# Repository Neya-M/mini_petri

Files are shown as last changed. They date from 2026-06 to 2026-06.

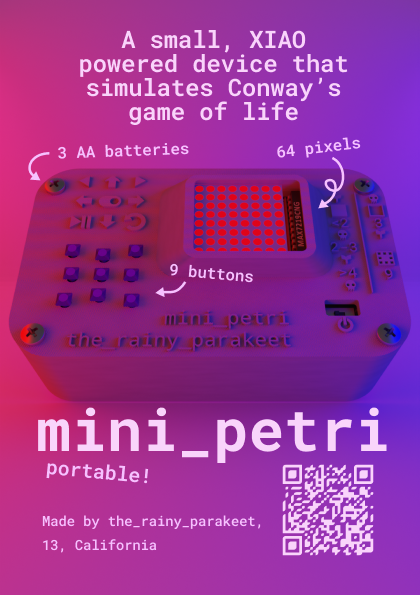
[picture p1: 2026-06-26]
images/zine/zine.png

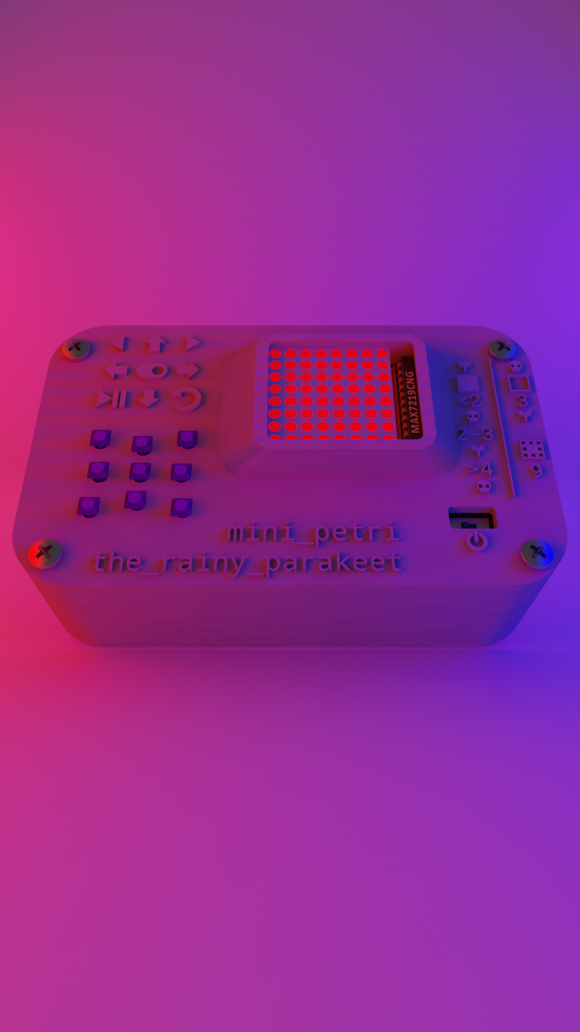
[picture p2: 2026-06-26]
images/render.png

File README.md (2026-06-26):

# Mini Petri

render of mini petri with case

Mini Petri is a device that simulates Conway's game of life. I got this idea during a particularly boring class when I wanted something satisfying to look at.

### Highlights

- runs on a Xiao RP2040 and 3 AA batteries
- 8x8 led dot matrix to give enough space for your life to grow
- 9 buttons to easily edit and play simulations 
- portable and pocket sized (8x13x5 cm)

Here is a banana for scale.

banana scale

## Build your own

render of mini petri pcb

Want a Mini Petri? Download the files in the "build" folder. Order the board with gerbers.zip. The case has 3d models in 2 different formats, STL and STEP. Put in the pushers on the underside of the lid and add the keycaps from the top. Use screws to attach the lid to the case. Load main.py onto the Xiao. That's it :)

I will add a more detailed assembly guide once I build it myself. 

## How to use

First, insert batteries and turn it on with the switch.

There are 9 buttons in a 3x3 arrangement for editing the starting positions and playing the simulation.

diagram of how it's used

## Conway's game of life

Conway's game of life is a simulation that uses a simple set of rules to create interesting patterns.

The rules:

each cell has 9 neighbors. A filled in or lit up cell is alive (depending on what you are using to simulate it).

each generation, cells are born and die based on their neighbors. 

A living cell with less than 2 living neighbors dies the next generation. If it has 2-3 living neighbors, it survives. If it has more than 3 living neighbors, it dies, as if by overpopulation.

A dead cell can be born if it has exactly 3 living neighbors, as if by reproduction.

With time, you can create really interesting structures such as "spaceships" that glide on indefinetly, "still life" structures where cells are never born and die, and "wires" that can transfer signals in the form of cells.





## Wiring
schematic

## Other

find the onshape file here: https://cad.onshape.com/documents/10df214650d10753392c4f94/w/a985103637e720fab81ebfaa/e/7306bce063d86ed0c220e238

Zine:
fallout zine

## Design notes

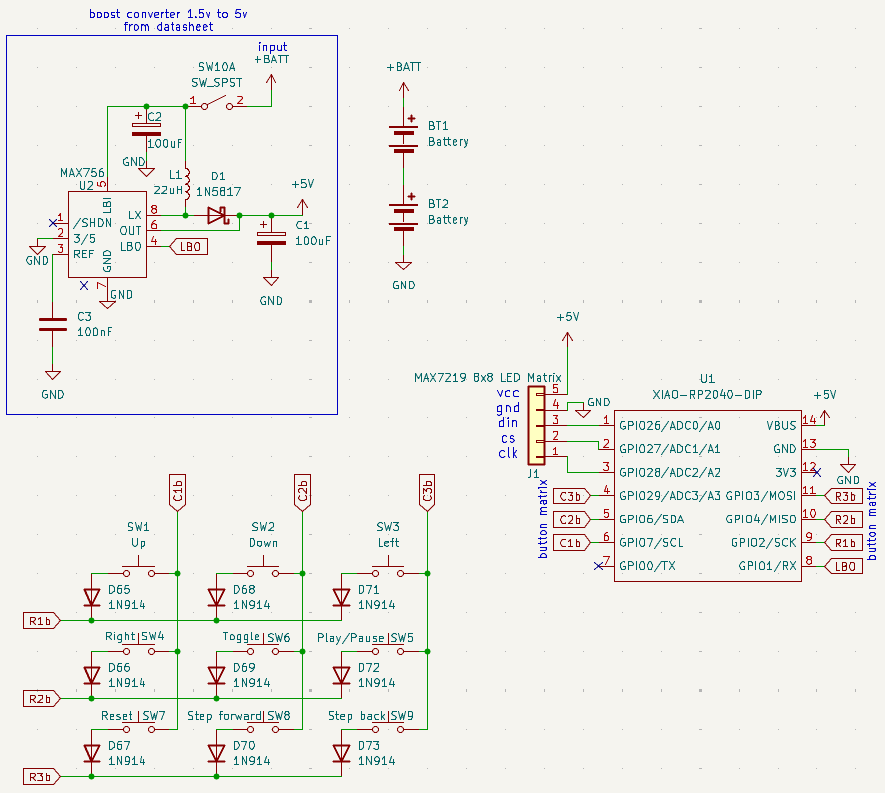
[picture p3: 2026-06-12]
images/Schematic.png

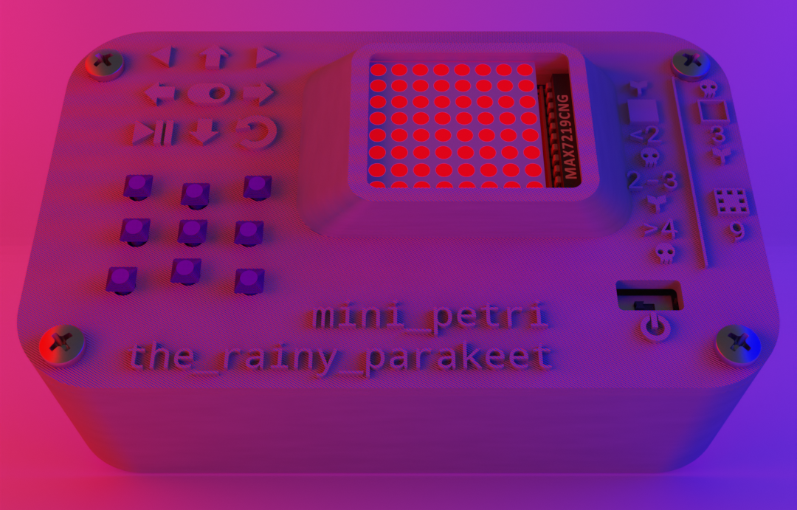
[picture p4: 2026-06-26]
images/render_small.png

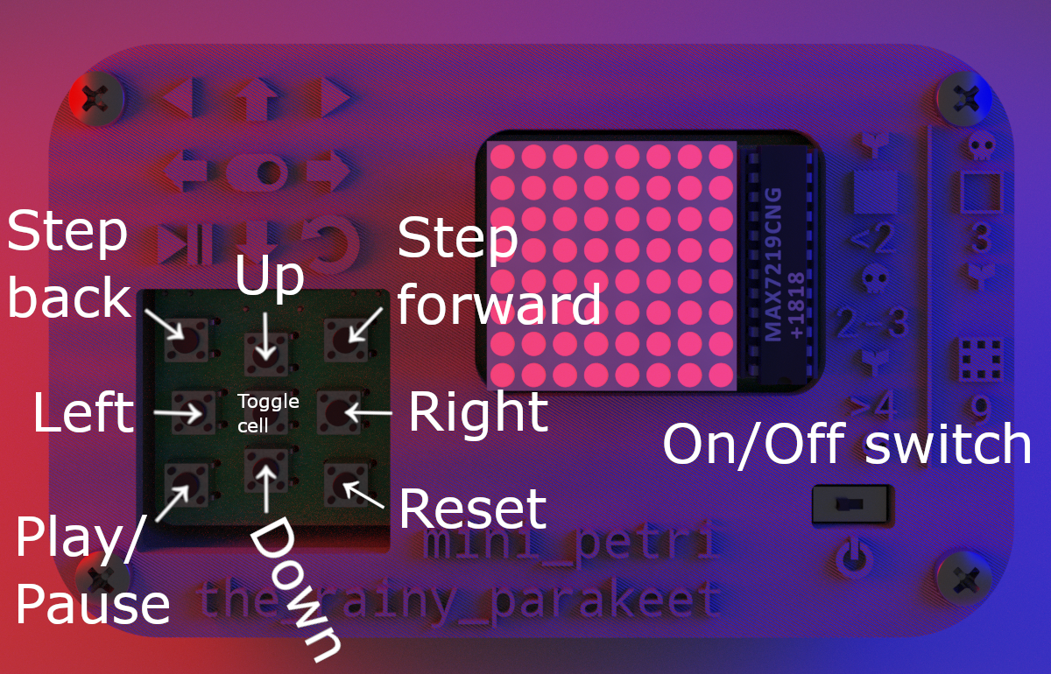
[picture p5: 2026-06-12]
images/UX_layout.png

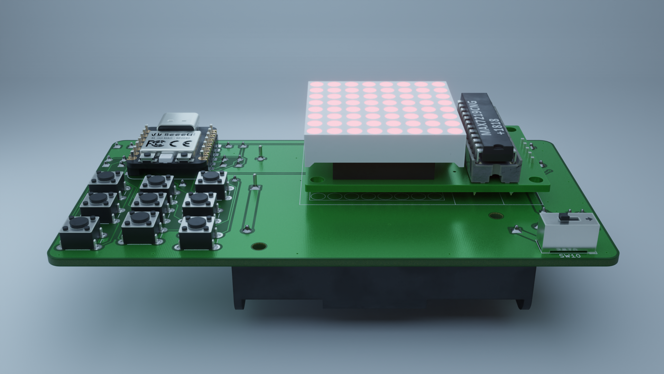
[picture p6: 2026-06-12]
images/pcb_render.png

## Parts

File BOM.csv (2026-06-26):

 | Part | Quantity | Links | Price | Shipping & Taxes | Total Price
1 | XIAO RP2040 THT | 1 | https://www.aliexpress.us/item/3256808815211592.html | $10.30 | $6.37 | $16.67
2 | MAX7219 8x8 LED Matrix | 1 | https://www.aliexpress.us/item/3256807297448326.html | $2.11 | $0.18 | $2.29
3 | Button switch 6mm | 9 | https://www.aliexpress.us/item/3256807058675649.html | $1.91 | $0.16 | $2.07
4 | Diode 1N914 | 9 | https://www.aliexpress.us/item/2251832393790143.html | $1.11 | $0.10 | $1.21
5 | SPST slide switch | 1 | https://www.aliexpress.us/item/3256806736595154.html | $4.36 | $0.19 | $4.55
6 | MAX756 | 1 | https://www.aliexpress.us/item/3256812216632031.html | $0.70 | $5.39 | $6.09
7 | Schottky diode 1N5817 | 1 | https://www.aliexpress.us/item/2251832838864425.html | $1.80 | $0.16 | $1.96
8 | Inductor 22 uH | 1 | https://www.aliexpress.us/item/3256806653531313.html | $0.55 | $5.41 | $5.96
9 | Capacitor 100 nF | 1 | https://www.aliexpress.us/item/3256807593821894.html | $2.45 | $0.14 | $2.59
10 | Capacitor 100 uF | 1 | https://www.aliexpress.us/item/3256806017188277.html | $2.67 | $0.16 | $2.83
11 | Capacitor 150 uF | 1 | https://www.aliexpress.us/item/2251832641693063.html | $3.64 | $0.31 | $3.95
12 | 2 AA battery holder | 1 | https://www.aliexpress.us/item/2255800821946138.html | $1.04 | $0.10 | $1.14
13 | 1 AA battery holder | 1 | https://www.aliexpress.us/item/2255800821946138.html | $1.00 | $0.10 | $1.10
14 | PCB | 1 | jlcpcb.com | $7.70 | $3.30 | $1.10
Totals |  |  |  | $41.34 | $22.07 | $53.51

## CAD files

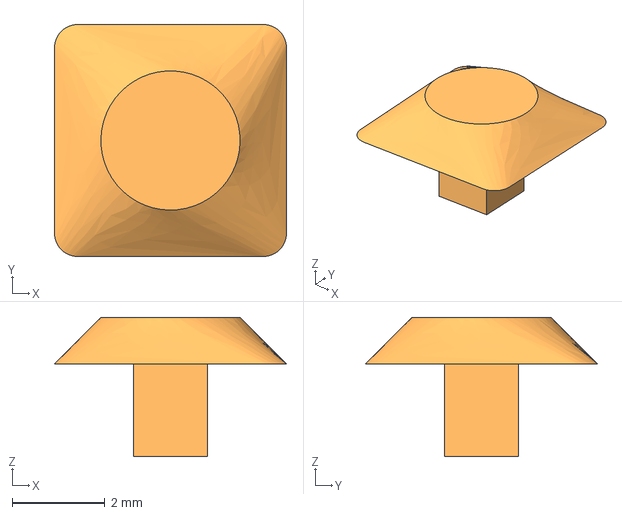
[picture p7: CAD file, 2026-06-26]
build/STEP/Keycap.step
5.00 x 5.00 x 3.00 mm

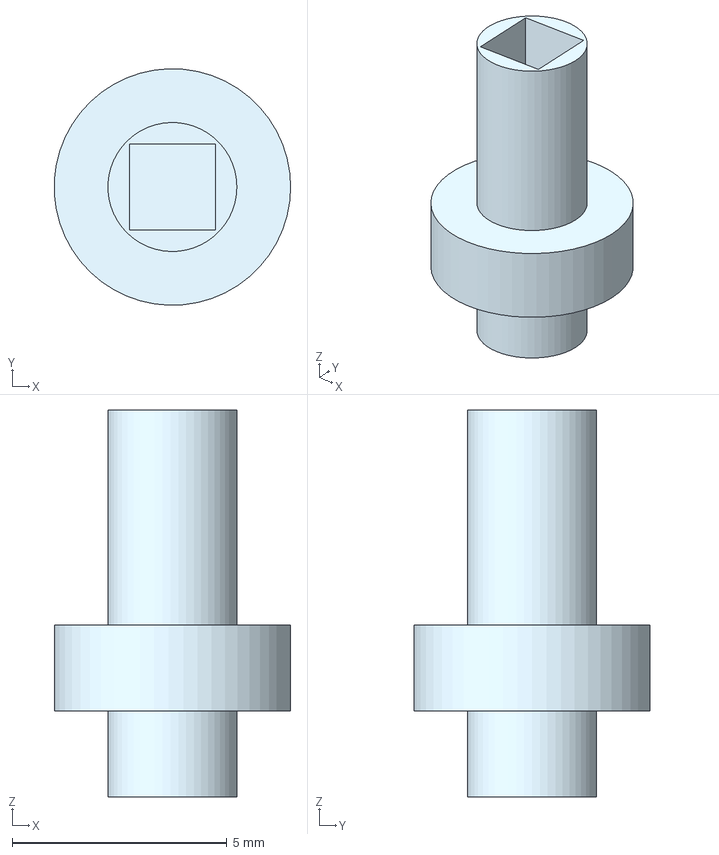
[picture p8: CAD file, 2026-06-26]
build/STEP/Pusher.step
5.49 x 5.50 x 9.00 mm

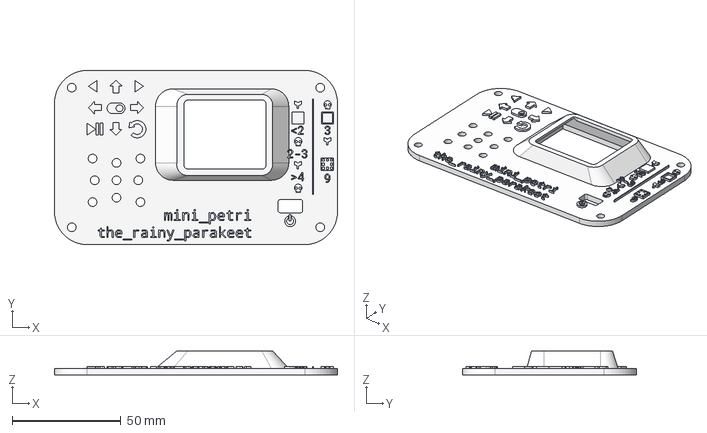
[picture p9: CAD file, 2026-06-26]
build/STEP/Lid.step
130.0 x 80.0 x 11.0 mm

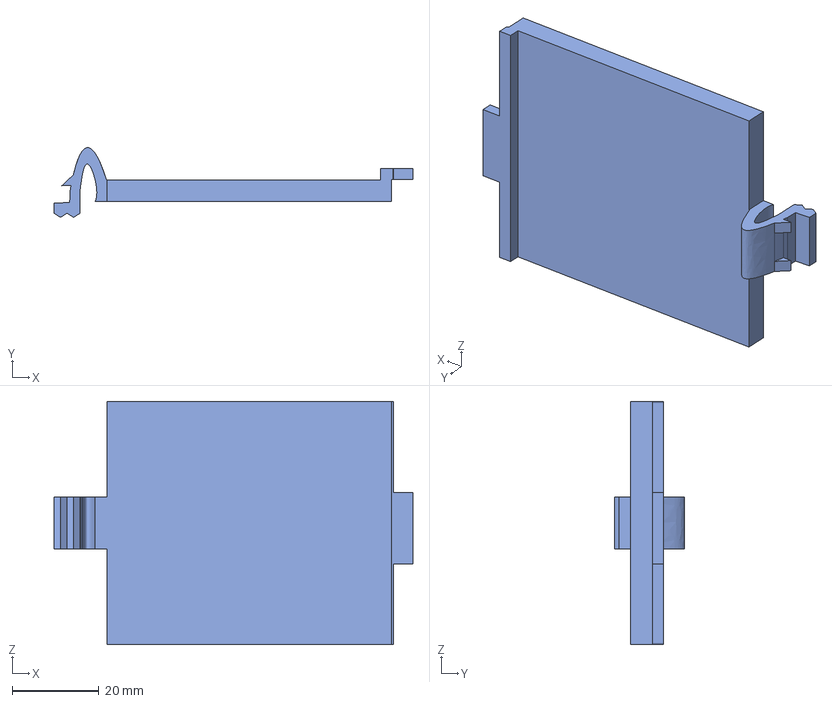
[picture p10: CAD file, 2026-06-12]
build/STEP/Battery_Cover.step
82.6 x 16.1 x 56.0 mm

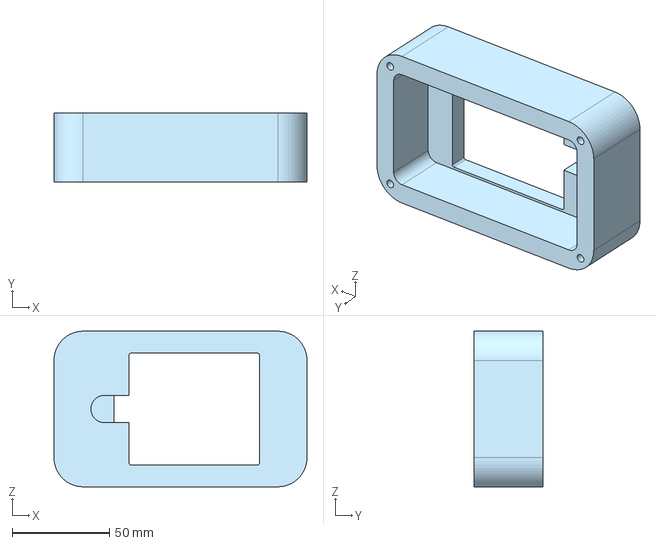
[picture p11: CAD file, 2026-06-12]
build/STEP/Case.step
130.0 x 35.5 x 80.0 mm

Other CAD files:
build/STL/Battery_Cover.stl
build/STL/Case.stl
build/STL/Keycap.stl
build/STL/Lid.stl
build/STL/Pusher.stl

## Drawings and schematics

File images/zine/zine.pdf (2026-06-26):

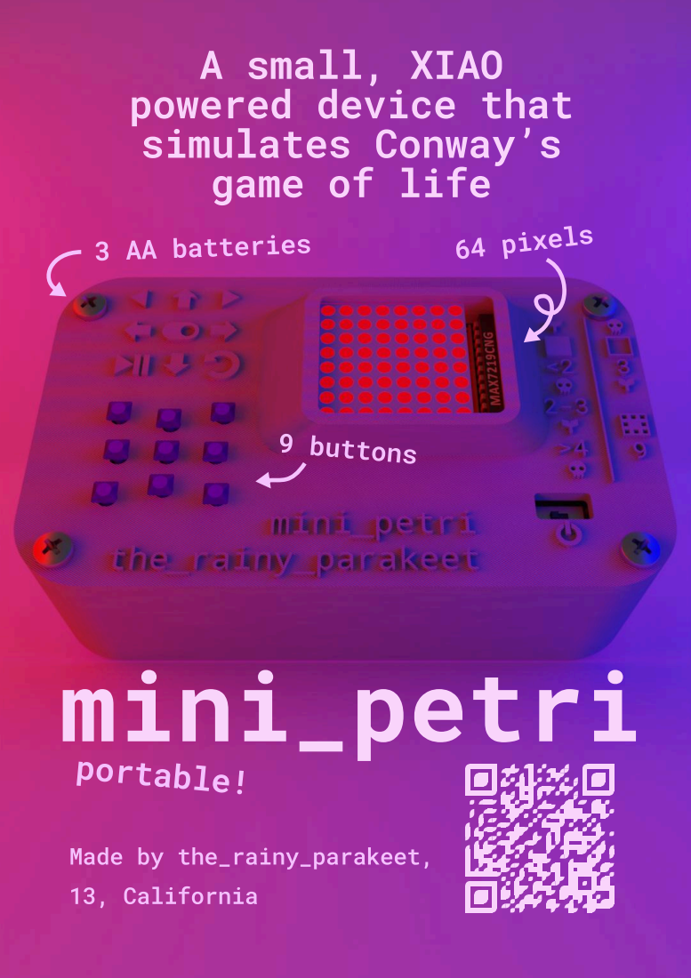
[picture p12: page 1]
9 buttons; mini_petri portable!; Made by the_rainy_parakeet,; 13, California

A small, XIAO powered device that simulates Conway’s game of life

3 AA batteries 64 pixels

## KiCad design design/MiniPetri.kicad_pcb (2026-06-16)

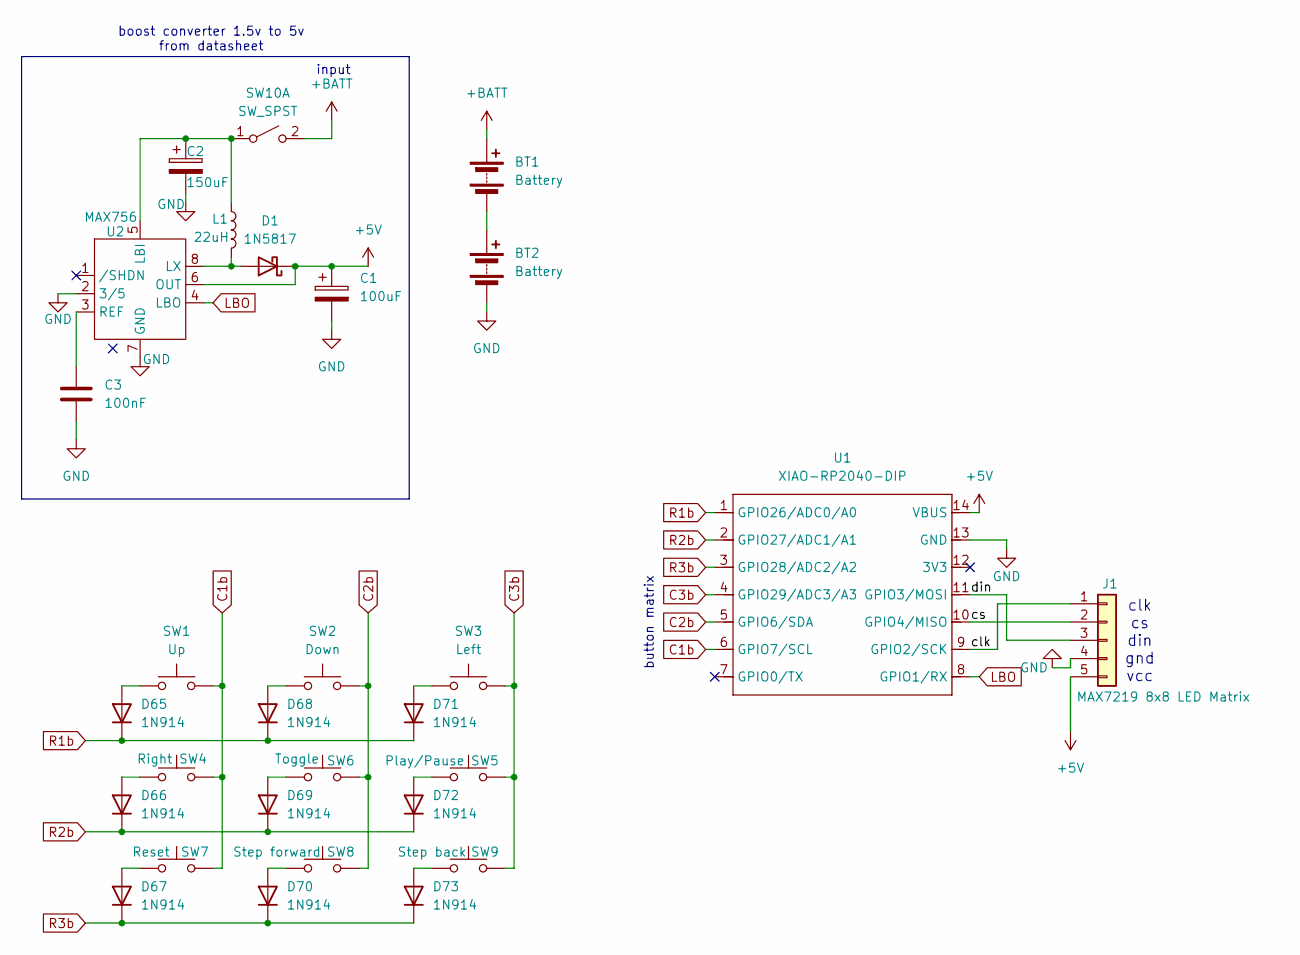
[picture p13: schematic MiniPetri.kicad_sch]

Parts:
BT1: Battery; BatteryHolder_Keystone_2460_1xAA
BT2: Battery; BatteryHolder_Keystone_2462_2xAA
C1: 100uF; CP_Radial_D5.0mm_P2.50mm
C2: 150uF; CP_Radial_D5.0mm_P2.50mm
C3: 100nF; C_Disc_D12.5mm_W5.0mm_P10.00mm
D1: 1N5817; D_DO-41_SOD81_P10.16mm_Horizontal
D65, D66, D67, D68, D69, D70, D71, D72, D73: 1N914; D_DO-35_SOD27_P7.62mm_Horizontal
J1: MAX7219 8x8 LED Matrix
L1: 22uH; L_10.4x10.4_H4.8
SW1: Up; SW_PUSH_6mm
SW2: Down; SW_PUSH_6mm
SW3: Left; SW_PUSH_6mm
SW4: Right; SW_PUSH_6mm
SW5: Play/Pause; SW_PUSH_6mm
SW6: Toggle; SW_PUSH_6mm
SW7: Reset; SW_PUSH_6mm
SW8: Step forward; SW_PUSH_6mm
SW9: Step back; SW_PUSH_6mm
SW10: SW_SPST; SW_DIP_SPSTx01_Slide_9.78x4.72mm_W7.62mm_P2.54mm
U1: XIAO-RP2040-DIP
U2: MAX756; SOIC-8_3.9x4.9mm_P1.27mm

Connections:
+5V: C1.1, D1.1 (K), J1.5, U1.14 (VBUS), U2.6 (OUT)
+BATT: BT1.1 (+), SW10.2 (B)
/clk: J1.1, U1.9 (GPIO2/SCK)
/cs: J1.2, U1.10 (GPIO4/MISO)
/din: J1.3, U1.11 (GPIO3/MOSI)
C1b: SW1.2, SW4.2, SW7.2, U1.6 (GPIO7/SCL)
C2b: SW2.2, SW6.2, SW8.2, U1.5 (GPIO6/SDA)
C3b: SW3.2, SW5.2, SW9.2, U1.4 (GPIO29/ADC3/A3)
GND: BT2.2 (-), C1.2, C2.2, C3.2, J1.4, U1.13 (GND), U2.2 (3/5), U2.7 (GND)
LBO: U1.8 (GPIO1/RX), U2.4 (LBO)
unnamed: BT1.2 (-), BT2.1 (+)
unnamed: D1.2 (A), L1.2, U2.8 (LX)
unnamed: D65.2 (A), SW1.1
unnamed: D66.2 (A), SW4.1
unnamed: D67.2 (A), SW7.1
unnamed: D68.2 (A), SW2.1
unnamed: D69.2 (A), SW6.1
unnamed: D70.2 (A), SW8.1
unnamed: D71.2 (A), SW3.1
unnamed: D72.2 (A), SW5.1
unnamed: D73.2 (A), SW9.1
unnamed: C2.1, L1.1, SW10.1 (A), U2.5 (LBI)
unnamed: C3.1, U2.3 (REF)
R1b: D65.1 (K), D68.1 (K), D71.1 (K), U1.1 (GPIO26/ADC0/A0)
R2b: D66.1 (K), D69.1 (K), D72.1 (K), U1.2 (GPIO27/ADC1/A1)
R3b: D67.1 (K), D70.1 (K), D73.1 (K), U1.3 (GPIO28/ADC2/A2)

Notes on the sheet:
boost converter 1.5v to 5v from datasheet
input
button matrix
clk cs din gnd vcc

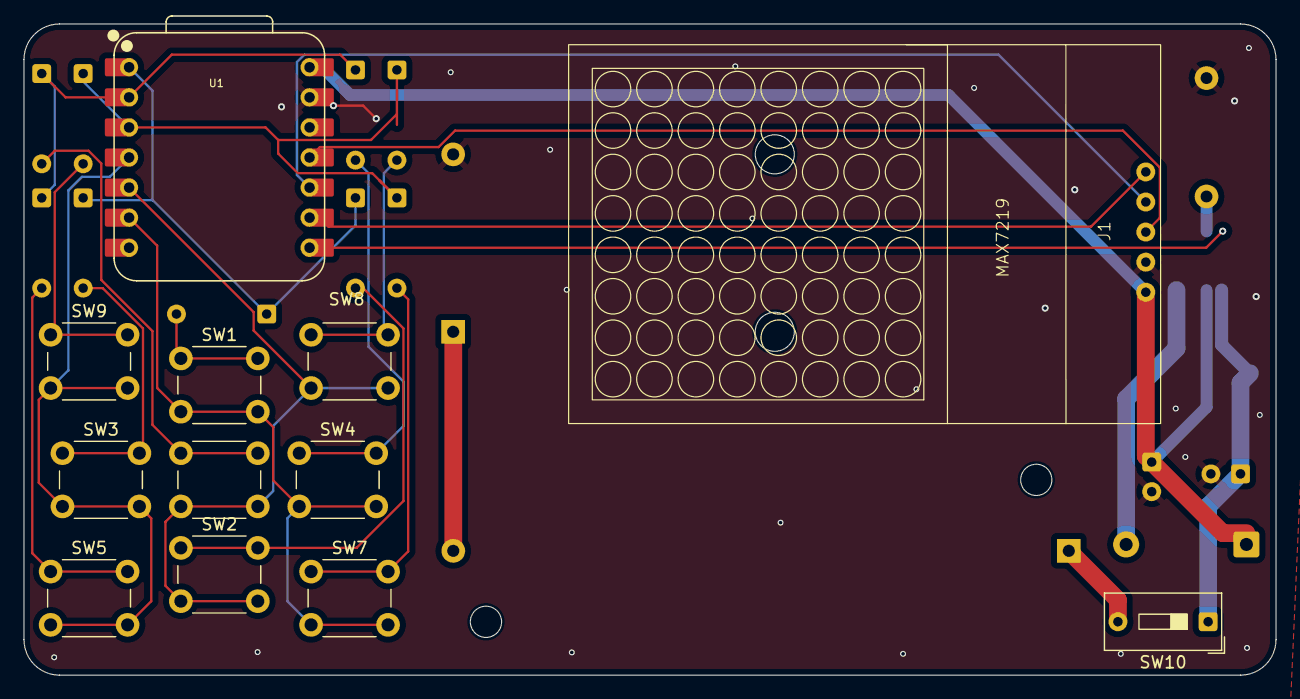
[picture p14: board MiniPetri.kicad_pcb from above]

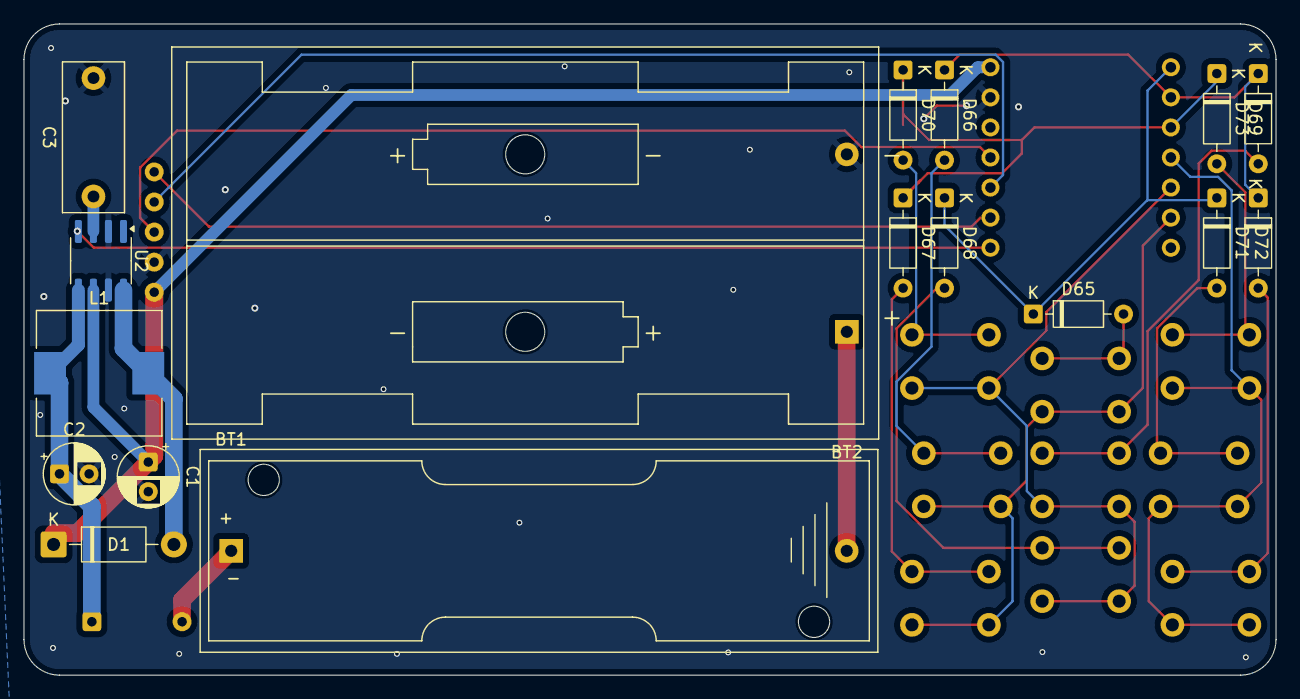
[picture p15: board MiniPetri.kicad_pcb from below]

Board: 2 copper layers, 105.8 x 55.0 mm, 29 parts (17 on the bottom side), 26 nets.

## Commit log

2026-06-13 finish up
    [BOM.csv, MiniPetri.kicad_pcb, MiniPetri.kicad_sch]
2026-06-16 add firmware
    [MiniPetri.kicad_pcb, MiniPetri.kicad_sch]
2026-06-18 another last minute fix
    [BOM.csv]
2026-06-26 make case nicer
    [BOM.csv, Keycap.step, Keycap.stl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]
